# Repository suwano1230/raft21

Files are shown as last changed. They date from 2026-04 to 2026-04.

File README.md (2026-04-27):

# raft21（ソクタイプ型のDIYキーボード）


## 概要
Stenturaプロトコル互換で動くソクタイプ型のDIYキーボードです。  
ソクタイプは21キーで、キーの配置やキーキャップのサイズ、表面のくぼみ、高低差があるなどの特徴があります。  
Ploverでの動作は確認できましたが、Stenturaプロトコルと同一のものではありません。  
実機などから情報を得てStenturaプロトコルを再現したということはありません。  
また、キーキャップのサイズなどに関して、ソクタイプの厳密な再現とは言えない可能性があります。  
## PCB基盤
KiCadを使用して作成。MCUはRP2040（Raspberry Pi Pico）を使用します。  
MCUはピンヘッダを使わない直接はんだ付け、基盤の厚さは1.6mm厚の前提でケースを設計しています。
## スイッチプレート
KiCadを使用して作成。基盤を発注するのと同様に発注します。1.6mm厚の前提でケースは作成しています。
## キーキャップ
ソクタイプ型のキーキャップを再現するために3Dプリンターで作成します。
## ケース
3Dプリンターで作成します。`bottom-case.stl`
## 製作に必要なもの（上記以外）
| 名称　　　　  | 個数　　　　  | 備考 　　　　 
|:---:|:---:|:---:|
| Raspberry Pi Pico  | 1 | Pico 2 ではない |
| PCBソケット  | 21 |スイッチを直接はんだ付けするなら不要|
| Cherry MX互換スイッチ  | 21 | 赤軸静音推奨　　　　 |
| プレートマウントスタビライザー 2U | 4 | MX用 |
| M2 6mm ねじ | 7 | 底用ねじ |
| M2 4mm ねじ | 7 | 天用ねじ |
| M2 8mm スペーサー  | 7 | 外径4.0mm以下 |
| Micro USB ケーブル  | 1 | データ転送対応のもの |
| ゴム足 10mm  | 4 | 　高さ任意　　　 |

※PCBソケット（使用しないならスイッチ）と Raspberry Pi PicoをPCB基盤にはんだ付けする必要があります。

※両手の人差し指側につけるスタビライザーは、接触する箇所があります。  
　適宜ニッパー等でカットし、接触しないようにする必要があります。

※キースイッチとばねをルブ（潤滑）するなら、キースイッチ用とばね用の潤滑剤が必要です。

※キースイッチのばねを取り替えるなら、それも必要です。  
　赤軸静音使用時、20g 14mmは戻る力がぎりぎり足りませんでした。  
　19g 22mmはぎりぎりセーフでした。長期の使用に耐えるかは不明です。

## uf2ファイル
BOOTSELボタンを押しながらUSBケーブルを接続し、Raspberry Pi Picoを書き込みモードで立ち上げ、そのフォルダ内にuf2ファイルをコピーすることで書き込みできます。

## 参考
- [Plover](https://github.com/opensteno/plover)  
- [電子速記研究会 （はやとくんの会）](https://www.hayatokun.com/)
- [電子速記はやとくん](https://www.youtube.com/@%E9%9B%BB%E5%AD%90%E9%80%9F%E8%A8%98%E3%81%AF%E3%82%84%E3%81%A8%E3%81%8F%E3%82%93/shorts)

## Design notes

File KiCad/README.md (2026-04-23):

## PCB基盤
`raft21_PCB.kicad_pcb`
## 回路図
ほかの設計を変更するとしても、ピンとスイッチの対応をこのファイルのとおりにすれば、uf2ファイルの書き込み後、期待どおりの動作をするはずです。`raft21_PCB.kicad_sch`
## スイッチプレート
`raft21_switchplate.kicad_pcb`
## PCB基盤のガーバーファイル
PCB基盤の発注時に必要なファイル一式。`raft21-PCB-gerber.zip` 
## スイッチプレートのガーバーファイル
スイッチプレートの発注時に必要なファイル一式。`raft21-switchplate-gerber.zip`

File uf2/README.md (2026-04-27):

- Stenturaプロトコル互換で動きます。Plover等のStenturaプロトコル互換対応のアプリケーションが必要です。また、実際に文字入力するためには体系化された辞書が必要になります。`raft21.uf2`  
- 符号をテキストとして出力します。PC側のアプリケーションを必要としません。符号を読むことができれば、後から反訳も可能です。また、符号から反訳できるアプリケーションがあれば、文字入力としても機能します。`raft21-sign-output-only.uf2`

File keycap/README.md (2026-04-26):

- ファイル名の末尾の数字が、raft21を１台作るのに必要な数です(合計21)。人差し指と親指で押すキー(＊を除く)は、キー間の距離を縮めるため、1mmずつ中心からずれています。

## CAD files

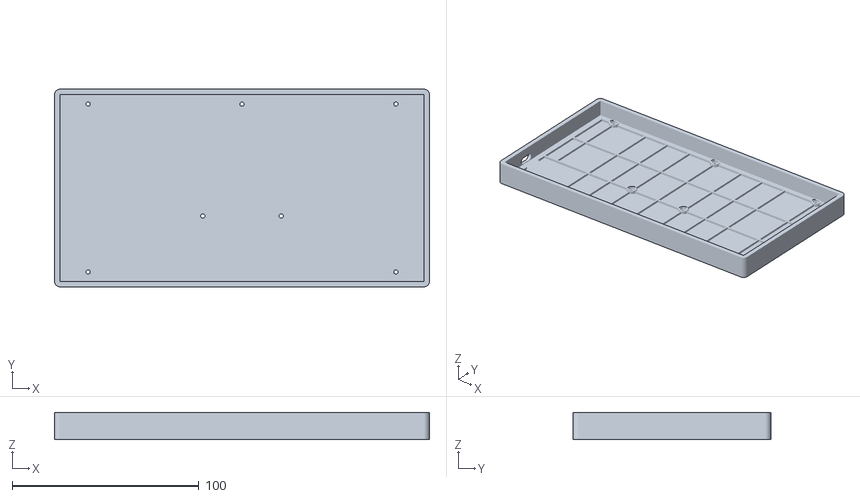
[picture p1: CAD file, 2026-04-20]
bottom-case.stl
201.0 x 106.0 x 14.6

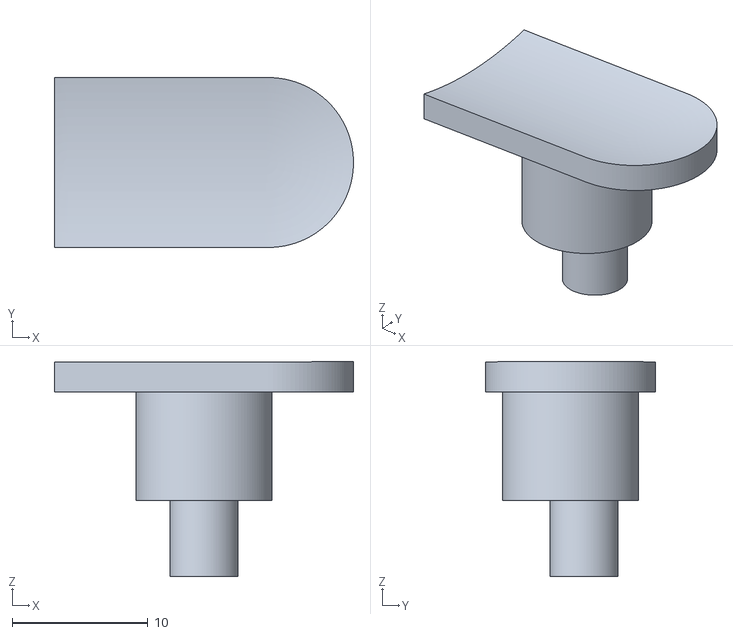
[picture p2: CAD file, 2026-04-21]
keycap/1u index finger2 2.stl
22.0 x 12.5 x 15.8

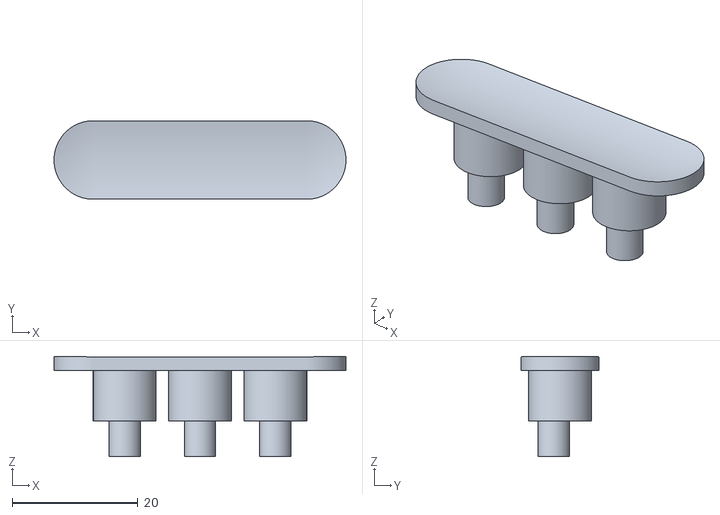
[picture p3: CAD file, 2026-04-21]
keycap/2u index finger 2.stl
46.5 x 12.5 x 15.9

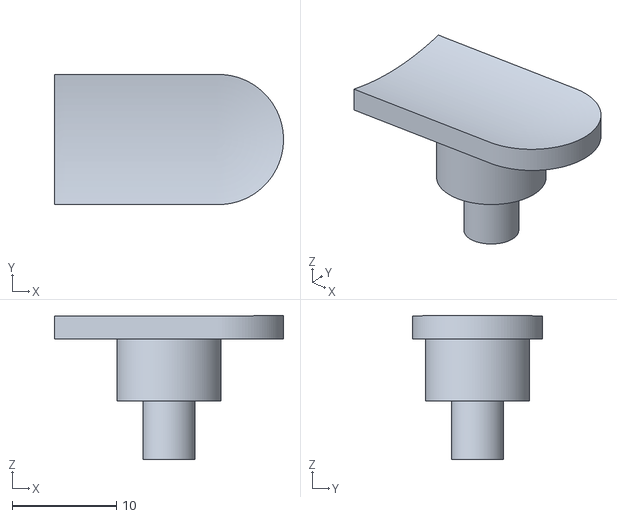
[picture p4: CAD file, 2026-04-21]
keycap/1u ring finger 4.stl
22.0 x 12.5 x 13.8

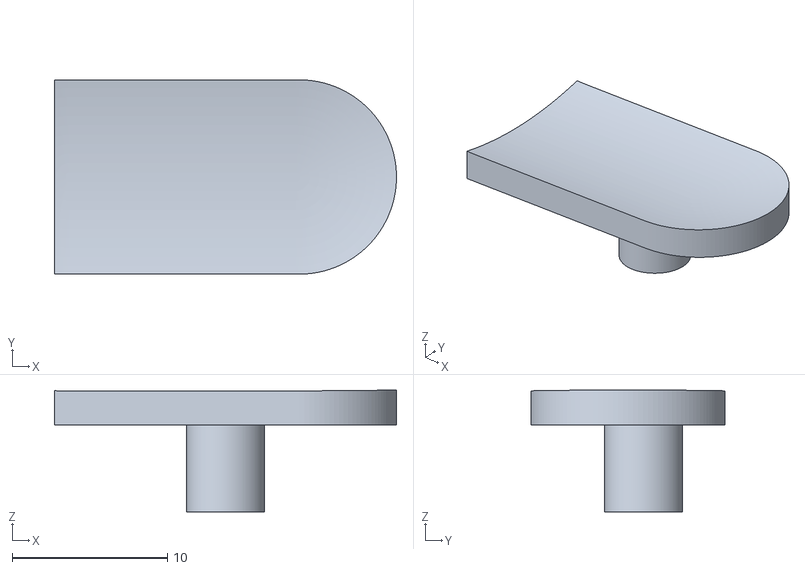
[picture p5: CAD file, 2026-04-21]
keycap/1u thumb1 2.stl
22.0 x 12.5 x 7.84

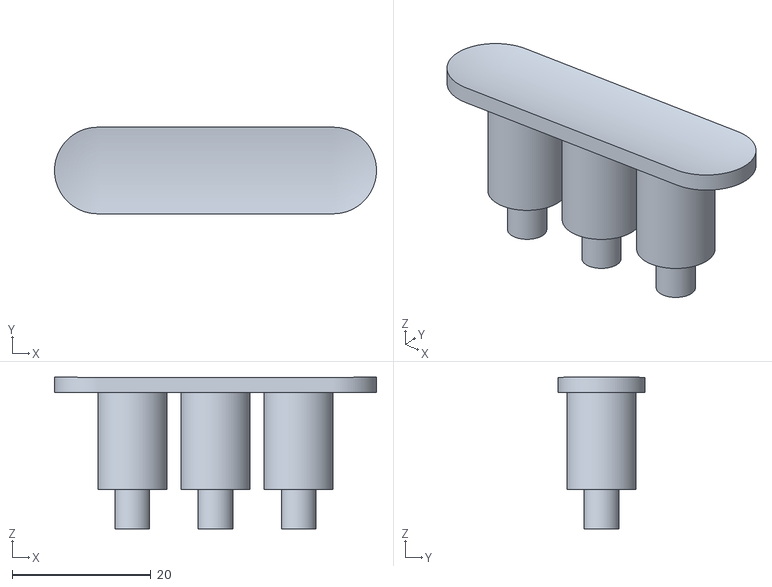
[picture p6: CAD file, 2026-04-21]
keycap/2u little finger 2.stl
46.5 x 12.5 x 21.9

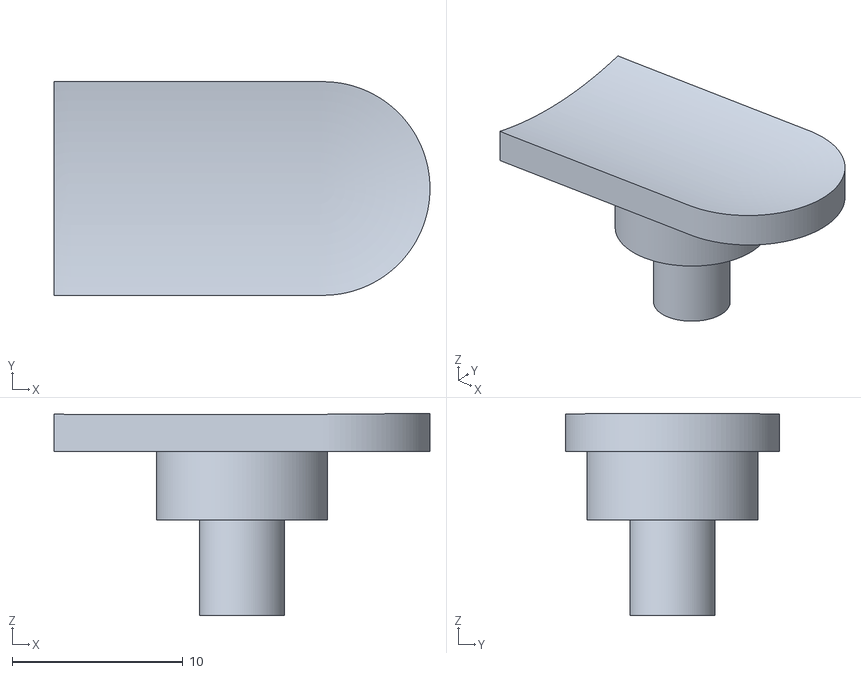
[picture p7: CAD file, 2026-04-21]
keycap/1u middle finger and star 5.stl
22.0 x 12.5 x 11.8

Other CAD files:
keycap/1u thumb2 2.stl
keycap/1u index finger1 2.stl

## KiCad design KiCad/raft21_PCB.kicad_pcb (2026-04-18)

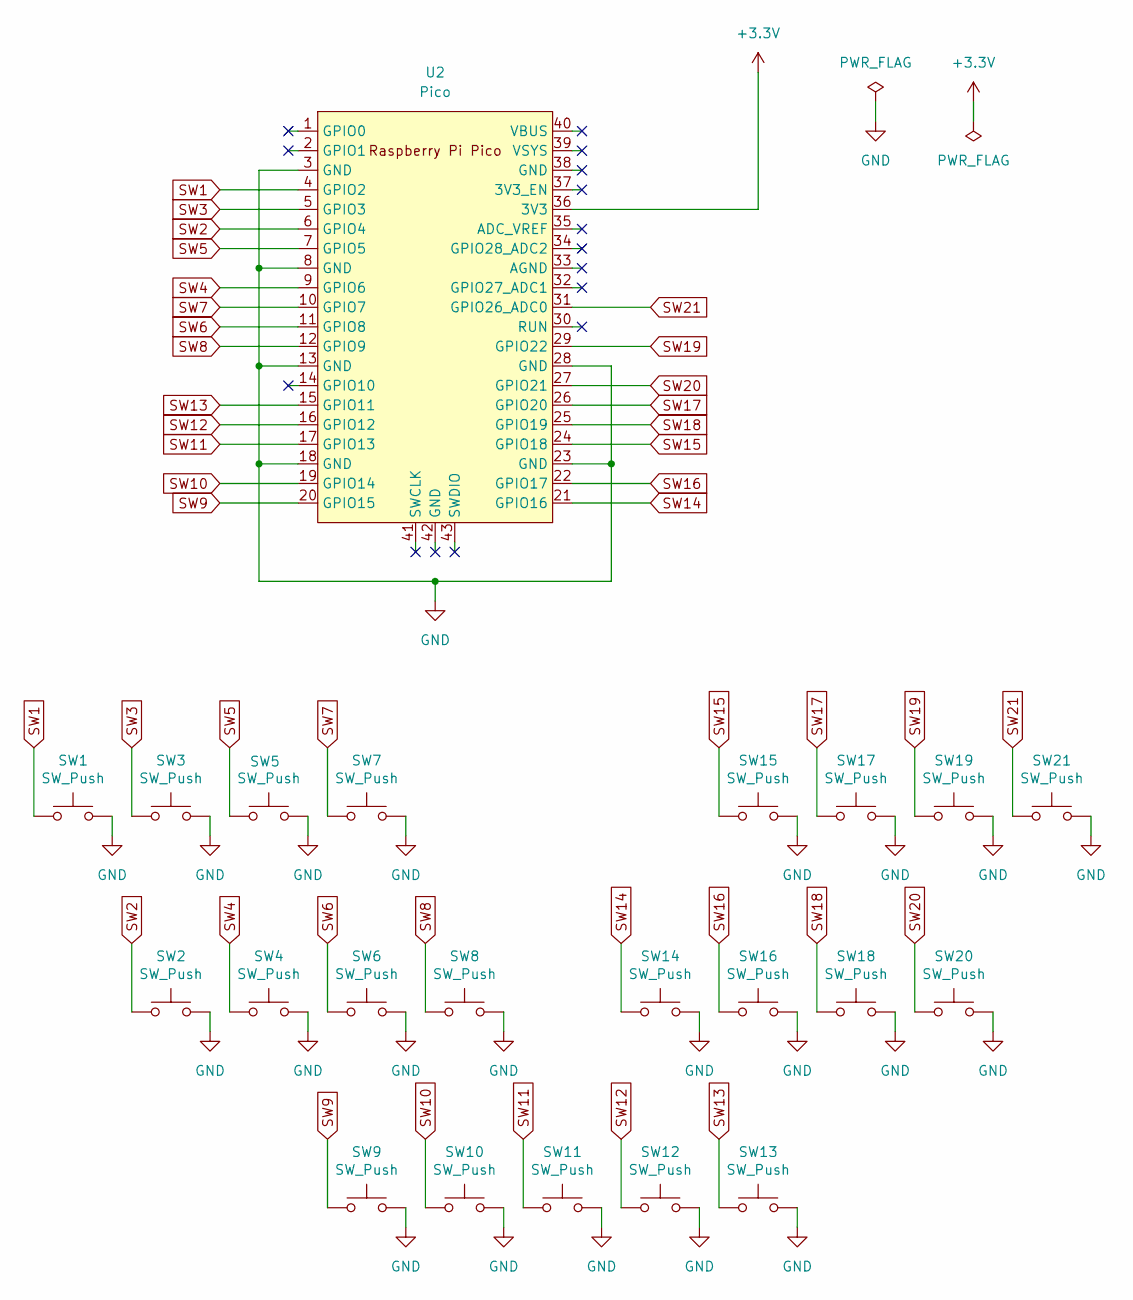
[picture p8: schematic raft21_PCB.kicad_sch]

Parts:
SW1, SW8, SW14, SW21: SW_Push; CherryMX_Hotswap_2.25u
SW2, SW3, SW4, SW5, SW6, SW7, SW9, SW10, SW11, SW12, SW13, SW15, SW16, SW17, SW18, SW19, SW20: SW_Push; CherryMX_Hotswap_1.25u
U2: Pico; RPi_Pico_SMD_TH

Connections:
+3.3V: U2.36 (3V3)
GND: SW1.2, SW2.2, SW3.2, SW4.2, SW5.2, SW6.2, SW7.2, SW8.2, SW9.2, SW10.2, SW11.2, SW12.2, SW13.2, SW14.2, SW15.2, SW16.2, SW17.2, SW18.2, SW19.2, SW20.2, SW21.2, U2.3 (GND), U2.8 (GND), U2.13 (GND), U2.18 (GND), U2.23 (GND), U2.28 (GND)
SW1: SW1.1, U2.4 (GPIO2)
SW2: SW2.1, U2.6 (GPIO4)
SW3: SW3.1, U2.5 (GPIO3)
SW4: SW4.1, U2.9 (GPIO6)
SW5: SW5.1, U2.7 (GPIO5)
SW6: SW6.1, U2.11 (GPIO8)
SW7: SW7.1, U2.10 (GPIO7)
SW8: SW8.1, U2.12 (GPIO9)
SW9: SW9.1, U2.20 (GPIO15)
SW10: SW10.1, U2.19 (GPIO14)
SW11: SW11.1, U2.17 (GPIO13)
SW12: SW12.1, U2.16 (GPIO12)
SW13: SW13.1, U2.15 (GPIO11)
SW14: SW14.1, U2.21 (GPIO16)
SW15: SW15.1, U2.24 (GPIO18)
SW16: SW16.1, U2.22 (GPIO17)
SW17: SW17.1, U2.26 (GPIO20)
SW18: SW18.1, U2.25 (GPIO19)
SW19: SW19.1, U2.29 (GPIO22)
SW20: SW20.1, U2.27 (GPIO21)
SW21: SW21.1, U2.31 (GPIO26_ADC0)

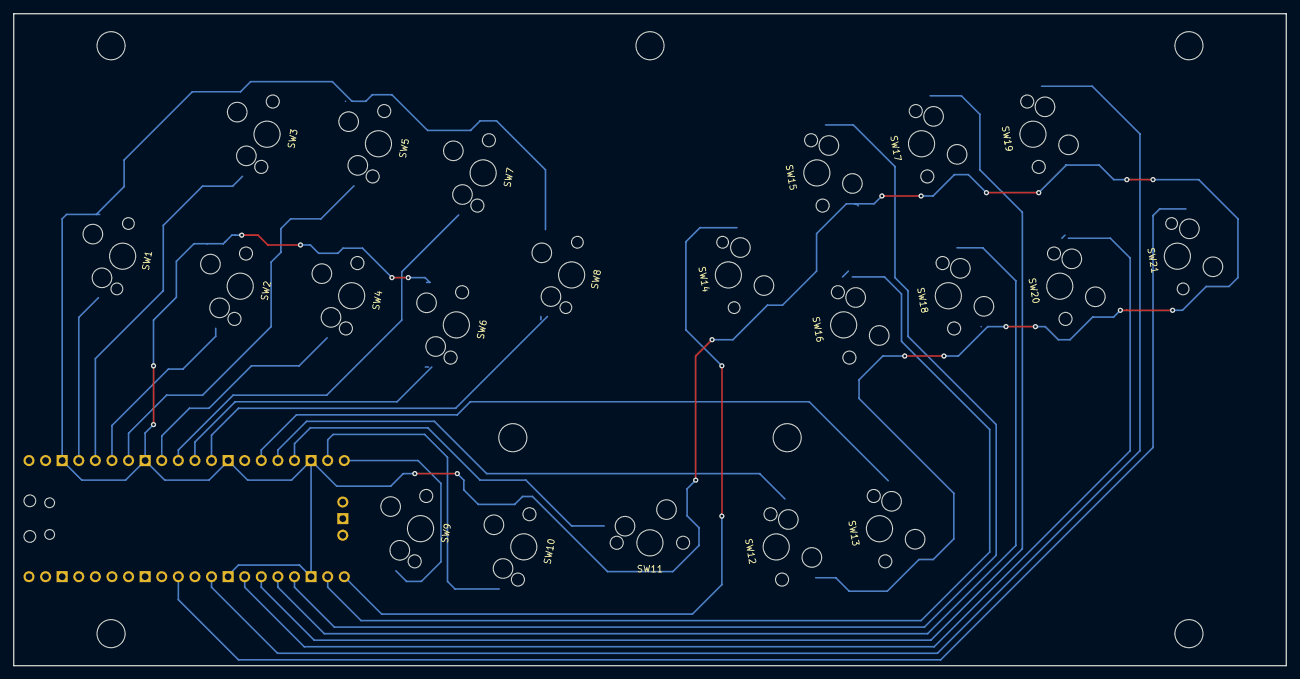
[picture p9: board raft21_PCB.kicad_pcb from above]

Board: 2 copper layers, 194.8 x 99.8 mm, 22 parts (1 on the bottom side), 22 nets.

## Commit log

2026-04-26 README.md を作成
2026-04-26 README.md を更新
